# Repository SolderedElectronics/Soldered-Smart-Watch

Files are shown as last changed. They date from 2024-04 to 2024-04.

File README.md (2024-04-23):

# Soldered Smart Watch Project

We can make our own weather stations, why not a smart watch? This project uses a Dasduino CONNECTPLUS, OLED Display and Gyroscope to create this wearable digital watch which also counts your daily steps.

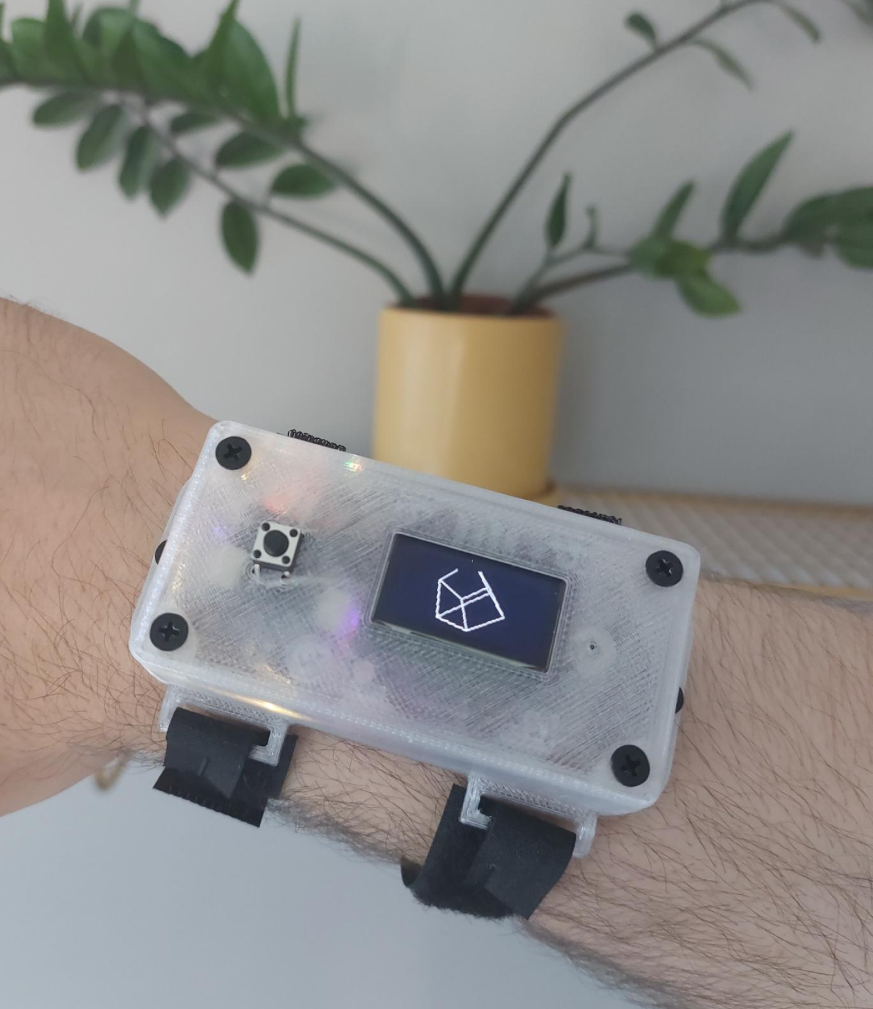
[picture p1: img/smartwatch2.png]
Smartwatch, but a nicer photograph


Here's a detailed tutorial on how to make one:

## Required tools

If you're printing the case yourself, a 3D printer is required. Use any fillament of your choice.
To assemble all the components, you will also need a soldering iron and a M3-compatible screwdriver.

## Components and materials

Here's the list of components used for this project:

| **Komponenta** | **URL** |
|---|---|
| Dasduino CONECTPLUS | [Solde.red/hr/333169](Solde.red/hr/333169) |
| OLED I2C 0.96" SSD1306 | [Solde.red/hr/333099](Solde.red/hr/333099) |
| Akcelerometar i žiroskop LSM6DS3 | [Solde.red/hr/333115](Solde.red/hr/333115) |
| Tipkalo | [Solde.red/hr/101111](Solde.red/hr/101111) |
| Li-ion baterija 680mAh 3.7V | [Solde.red/hr/333280](Solde.red/hr/333280) |
| 9 x Vijak M3 6mm | [Solde.red/hr/108941](Solde.red/hr/108941) |
| 9 x Navojni umetak M3 3mm | [Solde.red/hr/100761](Solde.red/hr/100761) |

You will also need a 47k Ohm and a 100k Ohm resistor and some spare wire.

## Compile and upload

To compile and upload the code, we reccomend using Arduino 1.8.x (legacy), which you can download [here](https://www.arduino.cc/en/software/OldSoftwareReleases/).

You will need to install the [Dasduino board definitions](https://github.com/SolderedElectronics/Dasduino-Board-Definitions-for-Arduino-IDE), as well.

The required libraries to compile the code are:
| **Library Name** | **URL** |
|---|---|
| Soldered OLED Display Library | [Link](https://github.com/SolderedElectronics/Soldered-OLED-Display-Arduino-Library) |
| Soldered LSM6DS3 Library | [Link](https://github.com/SolderedElectronics/Soldered-LSM6DS3-Arduino-Library) |
| Soldered WS2812 Library | [Link](https://github.com/SolderedElectronics/Soldered-WS2812-Smart-Leds-Arduino-Library) |
| RBD Button | [Link](https://github.com/alextaujenis/RBD_Button) |
| RBD Timer | [Link](https://github.com/alextaujenis/RBD_Timer) |

You will also need to edit the src/defines.h file with your relevant WiFi data and any other settings you may want to change.

To upload the code, open Soldered-Smart-Watch.ino, connect the Dasduino to your computer, select Soldered Dasduino CONNECTPLUS as the board, select the correct COM port and upload!

## Schematic

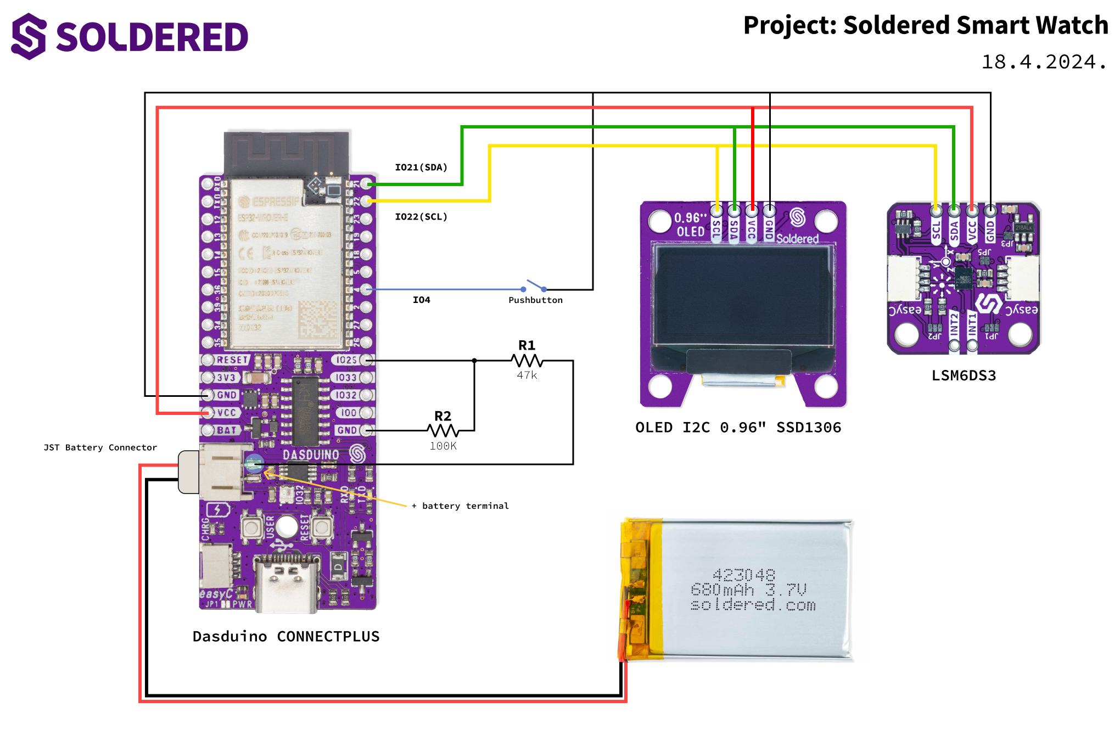
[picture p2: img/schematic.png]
Soldered Smart Watch Schematic


## Assembly

1. First, install the thread inserts in the pre-made holes. This is done with a soldering iron. Heat your soldering iron to 300 degrees Celsius, then, simply place the thread insert on top of the hole and press it slightly straight down with the soldering iron. The heat from the soldering iron will also heat up the thread insert and slightly melt the plastic around it, allowing the thread insert to slide in and stay perfectly:
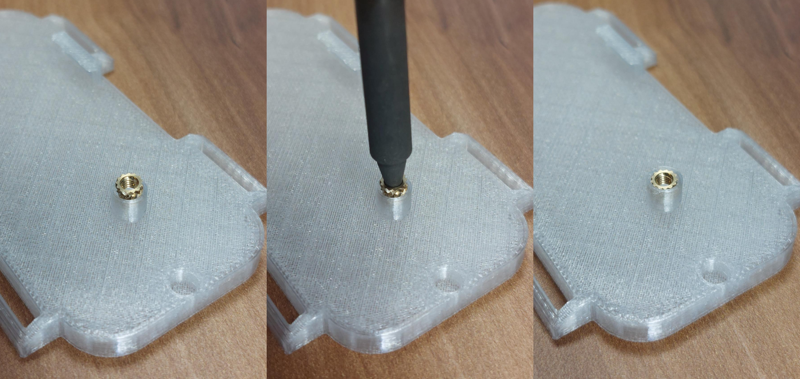
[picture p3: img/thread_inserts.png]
Thread Inserts Tutorial

2. Solder all the components together according to the schematic. Check the photo below for the approximate wire length. It can even be a bit shorter than this:
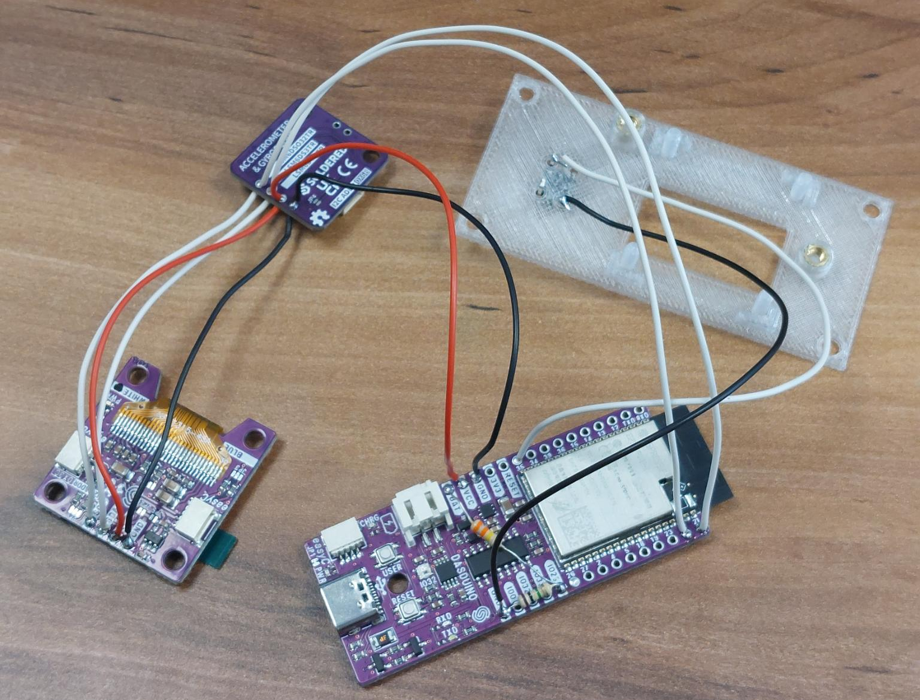
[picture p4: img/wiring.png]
Wiring

3. Place the battery in the battery slot in the bottom of the case. Screw in the Dasduino. Also, attatch the OLED display to the front of the case with the OLED holder. Screw in the gyroscope as well. Finally, in this step, place the sides of the case through the top so it can be screwed in place:
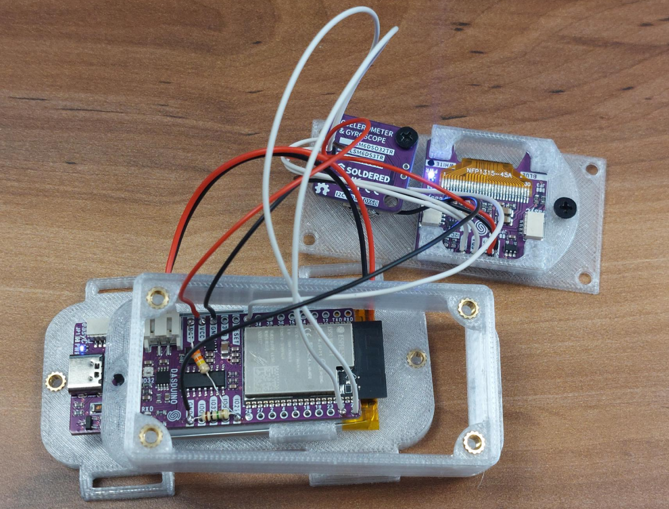
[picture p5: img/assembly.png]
Assembly

4. Screw the sides in and the top of the case. Finally, you can attatch some type of velcro or watch straps on the side, of your choice. You're done!
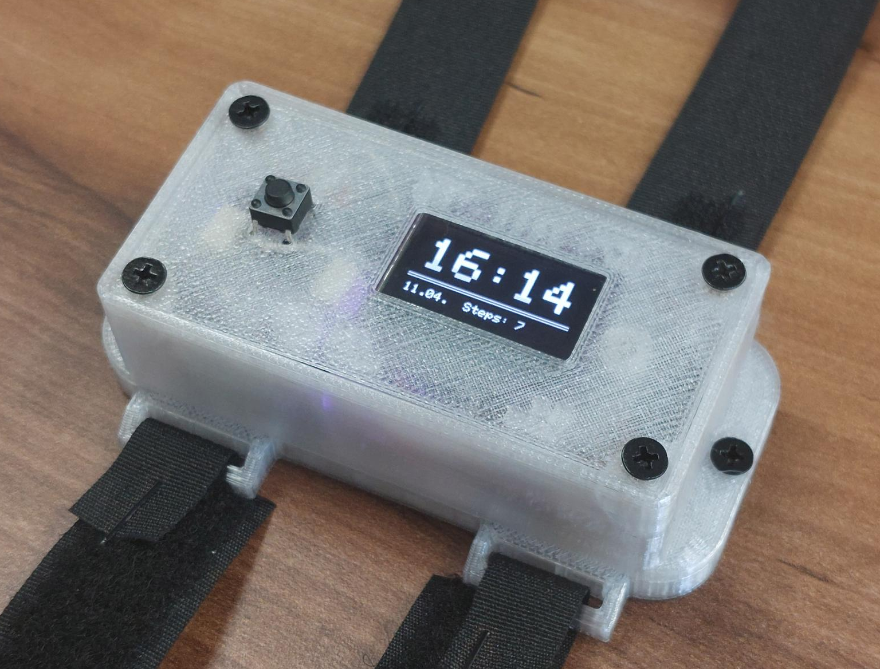
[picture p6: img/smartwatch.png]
Smartwatch


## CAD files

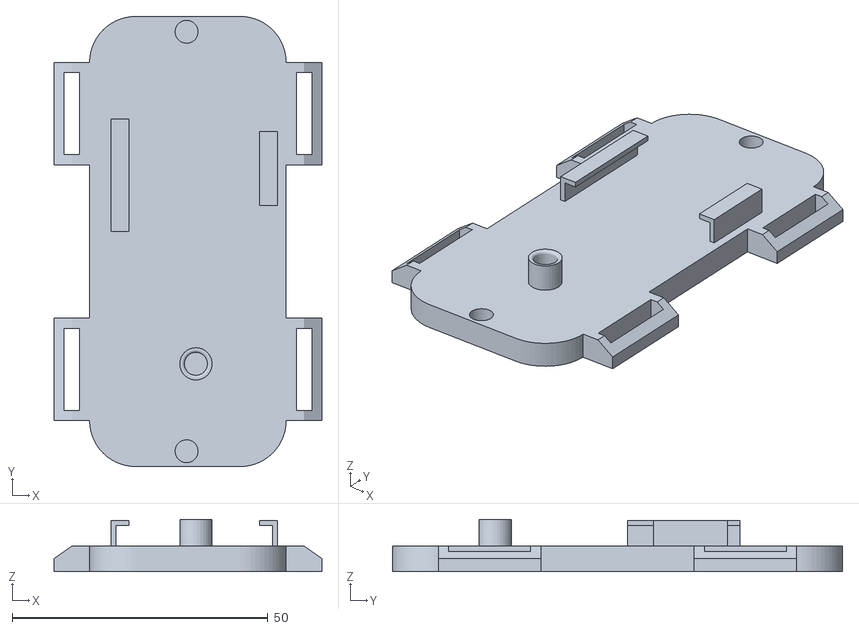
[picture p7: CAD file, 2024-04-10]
3D_printable_case/case_bottom.stl
52.4 x 88.0 x 10.2

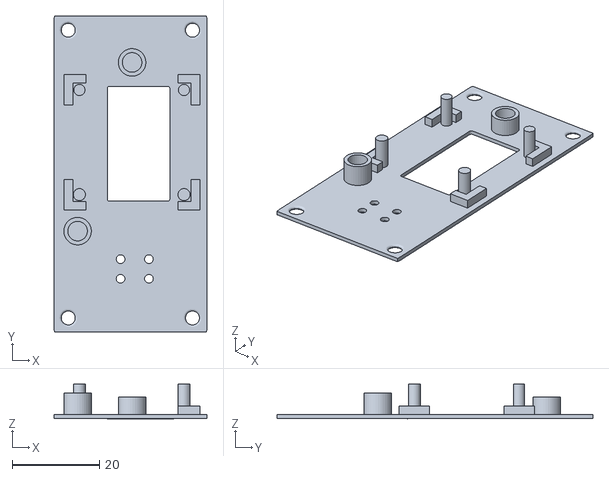
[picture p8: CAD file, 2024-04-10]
3D_printable_case/case_front_plate.stl
35.1 x 72.5 x 8.00

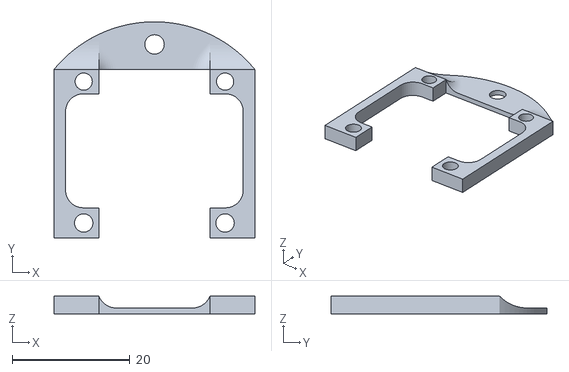
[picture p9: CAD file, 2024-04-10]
3D_printable_case/case_oled_holder.stl
34.1 x 36.7 x 3.00

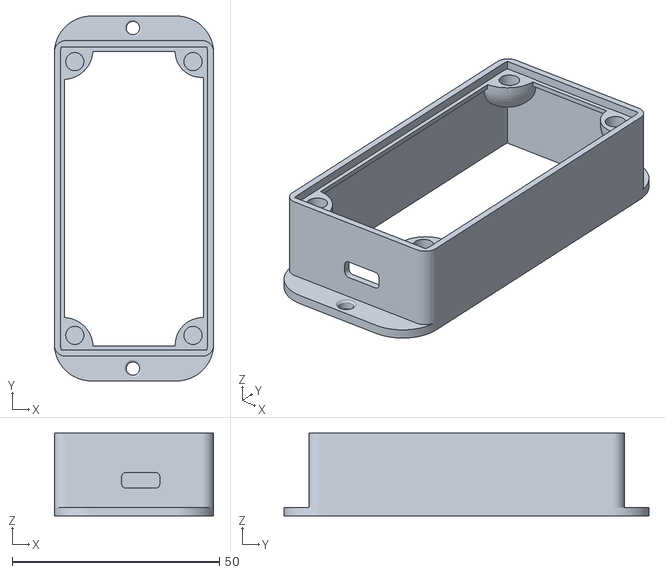
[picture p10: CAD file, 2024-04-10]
3D_printable_case/case_sides.stl
38.5 x 88.0 x 20.0

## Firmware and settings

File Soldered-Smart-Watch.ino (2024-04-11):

/**
 **************************************************
 *
 * @file        Soldered-Smart-Watch.ino
 * @brief       The main sketch file for the Soldered Smart Watch project. This sketch turns a Dasduino CONNECTPLUS with
 *an OLED display and a gyroscope into a smart watch. Check out the whole project with details on how to build it at
 *xyz.
 *
 * @note        Please check the README for library requirements to compile this sketch.
 *
 *              To build the project you will need:
 *              - Dasduino CONNECTPLUS: https://solde.red/333169
 *              - LSM6DS3 6-DOF breakout: https://solde.red/333115
 *              - OLED I2C 0.96" display: https://solde.red/333099
 *
 * @authors     Robert for soldered.com
 ***************************************************/

// This file is pretty important, it's for global defines and configurations
// If you want the watch to connect to your WiFi, you'll have to edit this file!
#include "src/defines.h"

// Include other external files and libraries
#include "LSM6DS3-SOLDERED.h" // Gyroscope library
#include "src/Display.h"      // Display driver
#include "src/Network.h"      // Network functions
#include "src/WSLED.h"        // Onboard RGB LED driver
#include "time.h"             // For storing time data
#include <RBD_Button.h>       // Button driver
#include <RBD_Timer.h>        // Required for button driver

// Let's declare objects which run the different features of the device
Network network;                // Network functions
Display display;                // OLED display
Soldered_LSM6DS3 gyro;          // Gyroscope
Wsled led;                      // RGB LED
RBD::Button button(BUTTON_PIN); // Button

// Local variable to remember the time when the RTC was last synchronized
time_t lastSyncAttemptTime;

// To check if the button was pressed
volatile bool buttonPressed = false;

// Let's remember the day of the week, so when it changes, we know to reset the step count
uint8_t lastRememberedWeekday = 0;

// Remember if low battery alert is active or not
bool lowBattery = false;

// Setup code, runs only once at startup
void setup()
{
    // Enable Serial communication if DEBUG is enabled
    if (DEBUG)
        Serial.begin(115200);

    // Print hello message to debug serial
    DEBUG_PRINT("Welcome to Soldered Smart Watch!");

    // Let's try to initialize the OLED display
    DEBUG_PRINT("Initializing OLED display...");
    if (!display.begin())
    {
        errorHandling("Couldn't initialize OLED display!");
    }
    DEBUG_PRINT("OLED display initialized!");

    // Let's try to initialize the OLED display
    DEBUG_PRINT("Initializing WSLED...");
    led.begin();
    DEBUG_PRINT("WSLED initialized!");

    // Let's initialize the gyroscope
    DEBUG_PRINT("Initializing gyroscope...");
    display.showLoadingMessage(OLED_GYRO_INIT_MSG); // Show a message on the OLED also
    if (gyro.beginCore() != 0)
    {
        // Couldn't init gyro!
        errorHandling(OLED_GYRO_INIT_ERROR_MSG);
    }
    // Now that the gyro is init'ed, also configure it!
    configGyro();

    // Let's attempt to connect to WiFi
    DEBUG_PRINT("Connecting to WiFi...");
    display.showLoadingMessage(OLED_WIFI_CONNECTING_MSG); // Show a message on the OLED also
    if (!network.connect(ssid, password, WIFI_CONNECT_TIMEOUT_SEC))
    {
        // Couldn't connect!
        errorHandling(OLED_WIFI_CONNECTING_ERROR_MSG);
    }
    DEBUG_PRINT("Connected to WiFi!");

    // Adding this delay helps to make sure we're fully connected to WiFi
    delay(1800);

    // Also, get the time and save it to RTC
    DEBUG_PRINT("Getting time...");
    display.showLoadingMessage(OLED_GETTING_TIME_MSG); // Show a message on the OLED also
    if (!network.getTimeAndSaveToRTC(ntpServer, timeZone, RTC_CONFIG_TIMEOUT_SEC))
    {
        // Couldn't get time from NTP server
        errorHandling(OLED_GETTING_TIME_ERROR_MSG);
    }
    DEBUG_PRINT("Got time and saved to RTC!");

    // Save the last sync attempt time
    lastSyncAttemptTime = time(nullptr);
    pinMode(BATTERY_VOLTAGE_PIN, INPUT);
}

// The main loop of the program
void loop()
{
    // Let's turn off the LED in case it was left on
    led.ledOff();

    // Let's check if low battery alert needs to be on:
    int batteryChargeStateValue = analogRead(BATTERY_VOLTAGE_PIN); // Read the analog value from pin 33
    if (batteryChargeStateValue <= LOW_BATTERY_ANALOG_READ)
    {
        lowBattery = true;
    }
    else
    {
        lowBattery = false;
    }

    // First, let's check if we need to re-sync the RTC via WiFi
    // Subtract the offset in seconds
    time_t currentTime = time(nullptr) - RTC_SECONDS_OFFSET;
    long timeDifference = difftime(currentTime, lastSyncAttemptTime);

    // Let's check if we need to reset the step count
    struct tm *timeinfo = localtime(&currentTime);
    int currentDayOfWeek = timeinfo->tm_wday;
    if (currentDayOfWeek != lastRememberedWeekday)
    {
        // First, save the day of the week
        lastRememberedWeekday = currentDayOfWeek;

        // Now reset the step count
        configGyro(); // Configuring the gyro resets the step count
    }

    // Let's get the currently measured number of steps
    uint32_t numSteps = getNumSteps();

    // Draw the current time and step count, and the low battery alert if so
    display.drawTimeAndStepCount(currentTime, numSteps, lowBattery);

    // Check if it's time to re-sync the RTC
    if (timeDifference >= RTC_SYNC_INTERVAL_SEC)
    {
        DEBUG_PRINT("Time to re-sync the RTC!");

        lastSyncAttemptTime = currentTime; // Remember the time a sync was attempted

        // Show the indicator on the display
        display.drawUpdatingRtcIndicator();

        // Set the flag to remember if we're connected to WiFi
        bool wifiConnected = false; // False by default

        // If we're not connected to Wi-Fi, re-connect
        if (!network.isConnected())
        {
            // If we can connect to WiFi, re-sync the RTC
            if (!network.connect(ssid, password, WIFI_CONNECT_TIMEOUT_SEC))
            {
                // Couldn't connect!
                DEBUG_PRINT("Couldn't connect to WiFi");
                // That's fine, we will keep RTC data
            }
            else
            {
                // Great, we're connected
                DEBUG_PRINT("Connected to WiFi!");
                wifiConnected = true; // Update the flag
            }
        }
        else
        {
            // We're already connected!
            wifiConnected = true;
        }

        if (wifiConnected)
        {
            // Now get the time and save it to RTC
            network.getTimeAndSaveToRTC(ntpServer, timeZone, RTC_CONFIG_TIMEOUT_SEC);
            DEBUG_PRINT("Updated time and saved to RTC!");
        }
    }

    // Now let's wait and periodically check for the button
    for (int i = 0; i < 500; i++)
    {
        // Wait 3 ms 500 times -> 1500 ms total
        delay(3);
        // If the flag was set in the meantime, do button action
        if (button.onPressed())
        {
            // Launch menu which selects feature
            DEBUG_PRINT("Button pressed - going to menu!");
            menu();
        }
    }
}

/**
 * @brief Print the error message on Serial and the OLED and then go to infinite loop
 *
 * @param error The string which describes the error
 */
void errorHandling(const char *error)
{
    DEBUG_PRINT(error);
    display.drawErrorMessage(error);
    // Go to infinite loop
    while (true)
    {
        // Restart the ESP if the button is pressed
        if (button.onPressed())
        {
            esp_restart();
        }
    }
}

/**
 * @brief Configure the gyroscope so it works as a pedometer
 * 
 * @note This function also resets the number of steps counted
 *
 */
void configGyro()
{
    uint8_t errorAccumulator = 0; // Error accumulation variable
    uint8_t dataToWrite = 0;      // Temporary variable

    // Configure range to lower range
    dataToWrite |= LSM6DS3_ACC_GYRO_FS_XL_2g;
    // Configure data rate
    dataToWrite |= LSM6DS3_ACC_GYRO_ODR_XL_26Hz;
    // Now, write the patched together data
    errorAccumulator += gyro.writeRegister(LSM6DS3_ACC_GYRO_CTRL1_XL, dataToWrite);

    // Set the ODR bit
    errorAccumulator += gyro.readRegister(&dataToWrite, LSM6DS3_ACC_GYRO_CTRL4_C);
    dataToWrite &= ~((uint8_t)LSM6DS3_ACC_GYRO_BW_SCAL_ODR_ENABLED);

    // Enable embedded functions -- ALSO clears the step count
    errorAccumulator += gyro.writeRegister(LSM6DS3_ACC_GYRO_CTRL10_C, 0x3E);
    // Enable pedometer algorithm
    errorAccumulator += gyro.writeRegister(LSM6DS3_ACC_GYRO_TAP_CFG1, 0x40);

    // If there was an error, go to error handling
    if (errorAccumulator)
    {
        errorHandling("Couldn't configure gyro!");
    }
}

/**
 * @brief Get the number of steps as measured by the gyroscope
 *
 * @return uint16_t
 */
uint16_t getNumSteps()
{
    // Create placeholder variables
    uint8_t readDataByte = 0;
    uint16_t stepsTaken = 0;

    // Read the 16bit value by two 8bit operations
    gyro.readRegister(&readDataByte, LSM6DS3_ACC_GYRO_STEP_COUNTER_H);
    stepsTaken = ((uint16_t)readDataByte) << 8;
    gyro.readRegister(&readDataByte, LSM6DS3_ACC_GYRO_STEP_COUNTER_L);
    stepsTaken |= readDataByte;

    // Return it!
    return stepsTaken;
}

/**
 * @brief The menu function, this is launched when the button is pressed
 * 
 */
void menu()
{
    // Start measuring time
    uint32_t timeout = millis();
    int menuPage = 0; // Start with 0 for first press
    
    // Show the menu page and color
    display.drawMenuPage(menuPage);
    led.showMenuColor(menuPage);

    // Go to infinite loop
    while (true)
    {
        // If the button is pressed, keep counting the menu pages
        if (button.onPressed())
        {
            menuPage++;

            // Watch if the pages roll over.
            if (menuPage >= 4)
            {
                menuPage = 0;
            }

            // Show the current page
            display.drawMenuPage(menuPage);
            led.showMenuColor(menuPage);
            
            // Reset the timer
            timeout = millis();
        }

        // When the timeout is over, launch  the according function
        if (millis() - timeout > MENU_TIMEOUT_MS)
        {
            if (menuPage == 0)
            {
                display.wifiScanner(&button);
                return;
            }
            else if (menuPage == 1)
            {
                display.gyroAnimation(&gyro, &button);
                return;
            }
            else if (menuPage == 2)
            {
                // "Self destruct"
                customFunction();
                return;
            }
            else
            {
                // Go back
                return;
            }
        }
    }
}

/**
 * @brief Write your own implementation here!
 * 
 */
void customFunction()
{
    // Count 3... 2... 1...
    for (int i = 3; i >= 0; i--)
    {
        display.selfDestructMessage(i);

        // The blinks are 200ms, so 5 blinks for 1 second
        led.redBlink();
        led.redBlink();
        led.redBlink();
        led.redBlink();
        led.redBlink();
    }

    // Show that self destruct is over
    display.selfDestructEnd();
    delay(5000); // Wait so that the user sees the message
}

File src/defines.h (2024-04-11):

#ifndef __SMART_WATCH_DEFINES__
#define __SMART_WATCH_DEFINES__

// Set this to false if you don't want debug messages printed on Serial
// Messages are printed at 115200 baud rate
#define DEBUG true
// Function which prints debug via Serial
#define DEBUG_PRINT(x)                                                                                                 \
    if (DEBUG)                                                                                                         \
    {                                                                                                                  \
        Serial.println(x);                                                                                             \
        Serial.flush();                                                                                                \
    }

// WiFi credentials
// The smart watch will attempt to connect to this WiFi to re-sync the time
const static char *ssid = "Soldered";
const static char *password = "dasduino";

// NTP server to use for time synchronization
const static char *ntpServer = "pool.ntp.org";

// Timezone setting for Zagreb, Croatia
// For a list of possible time zones, check zones.csv
const static char *timeZone = "CET-1CEST,M3.5.0,M10.5.0/3";

// Some timeout settings
#define WIFI_CONNECT_TIMEOUT_SEC 10
#define RTC_CONFIG_TIMEOUT_SEC   10

// How often to attempt to re-sync the RTC via WiFi
#define RTC_SYNC_INTERVAL_SEC 2 * 3600 // Sync every 2 hours by default

// An offset in seconds for the RTC
// You can use this to fine-tune the time saved to the RTC
#define RTC_SECONDS_OFFSET 10

// Timeout for the menu, before returning to the main loop
#define MENU_TIMEOUT_MS 1500

// Display settings
#define OLED_WIDTH  128
#define OLED_HEIGHT 64

// Button pin
#define BUTTON_PIN 4

// Battery voltage read pin
#define BATTERY_VOLTAGE_PIN 33

// The value of the ADC reading at which the low battery alert turns on
#define LOW_BATTERY_ANALOG_READ 2000

// Fixed display messages
// Spaces are in front because this makes them easier to print and align in the middle
#define OLED_WIFI_CONNECTING_MSG       "Connecting to WiFi..."
#define OLED_WIFI_CONNECTING_ERROR_MSG "Can't connect!"
#define OLED_GYRO_INIT_MSG             " Initializing gyro.."
#define OLED_GYRO_INIT_ERROR_MSG       "Can't init gyro!"
#define OLED_GETTING_TIME_MSG          "    Getting time..."
#define OLED_GETTING_TIME_ERROR_MSG    "Can't get time!"
#define MENU_PAGE_0_TEXT "     WiFi Scanner"
#define MENU_PAGE_1_TEXT " Gyroscope Animation"
#define MENU_PAGE_2_TEXT "    Self Destruct"
#define MENU_PAGE_3_TEXT "      Exit Menu"

#endif
